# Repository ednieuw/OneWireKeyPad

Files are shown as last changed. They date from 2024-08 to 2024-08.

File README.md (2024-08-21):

# 1x3 and 4x3 membrane keypad controlled with one wire to the analog pin

[Page as PDF](https://github.com/ednieuw/OneWireKeyPad/blob/main/One%20wire%203x4%20keypad.pdf)
<table>
<tr>
 <td>This page describes how to wire the output pins of a:<br />
<br />
- seven 
pins, 3 columns * 4 rows key pad <br />
<br />
<br />
and a <br />
</td>
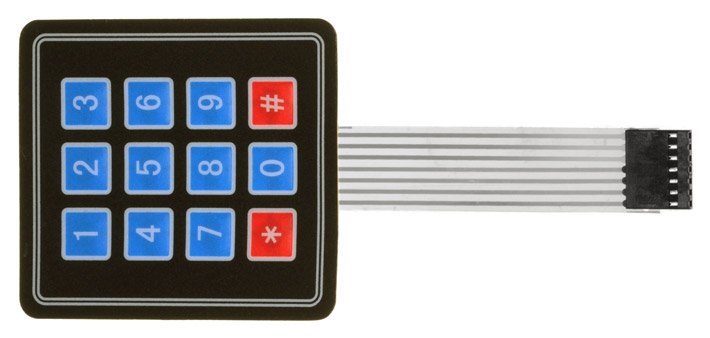
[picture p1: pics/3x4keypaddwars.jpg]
keypad
<td></td>
</tr>
<tr>
<td>
- four pins three button 3 x 1 keypad, <br />
	<br />
to an one wire analogue output.
	</td>
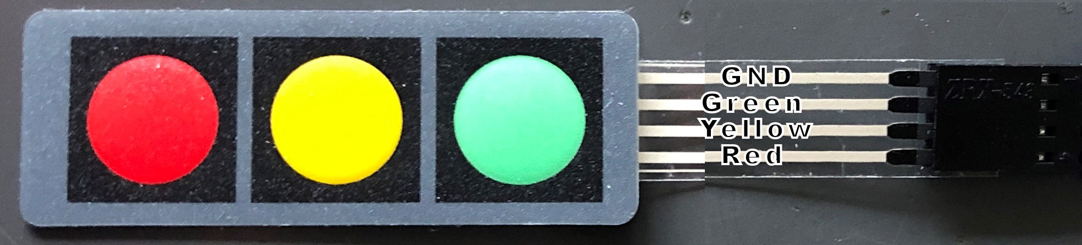
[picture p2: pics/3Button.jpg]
keypad 3b
<td></td>
	</tr>
</table>
<br />
The addition of a few resistors converts the key pads to one wire and saves 
many digital pins at the cost one analogue pin.<br />
Libraries are not needed anymore and will save many memory bytes but lacking 
interrupt driven detection of operation of the key pad. <br />
But processors are very fast and in many programs it is possible to check the 
buttons more than 1000 times a second.<br />
The three button key pad is a nice, flat, replacement of a rotary encoder saving 
three digital pins, a library and 1500 bytes.</p>
<br />
Three different resistor resistances are used.<br />
This page:
<a href="http://www.circuitbasics.com/how-to-set-up-a-keypad-on-an-arduino/">
http://www.circuitbasics.com/how-to-set-up-a-keypad-on-an-arduino/</a>
explains how the key pad works.<br />
<br />
There are many tutorials how to make a one-key wire keypad but or they use many 
resistors, make use of libraries or are hard to follow.</p>
<p>
<table>
<tr>
	<td> In the picture on the right one can see that by 
	pressing a button a connection is made between a row and a column. <br />
	By choosing the right resistor combination the output will be different 
	for every button. <br />
	5V is connected to C1 and ground after a 1.1 kilo-ohm resistor.<br />
	When 3 is pressed the current flows from R1 tot C3 and flows to a 1.1 
	kilo-ohm resistor resulting in a reading of 989 bits. <br />
	Pressing * R4 and C1 and connected resulting in a flow through all the 
	resistors and a reading of 125 bits.<br />
	To discriminate between the buttons the difference between the 
	difference button must be as large as possible.<br />
	Because resistors of identical resistance value will not have exact the 
	same resistance measured, readings between modules will vary a little. 
	In the Arduino source code the range per button is large enough to 
	overcome these differences. </td>
	<td >
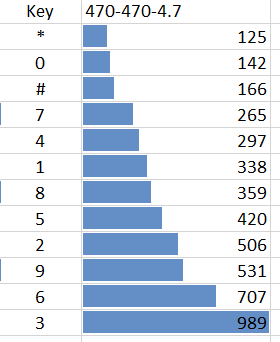
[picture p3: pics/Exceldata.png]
Analogue readings
 		</td>
	<td>
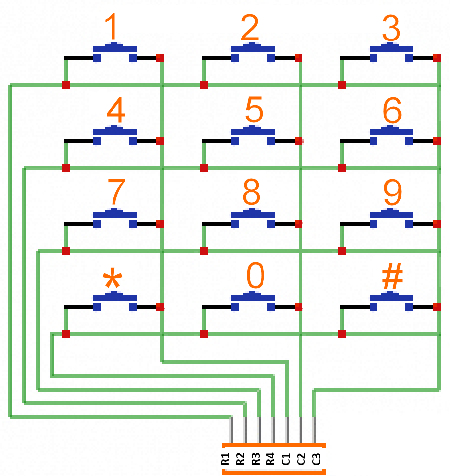
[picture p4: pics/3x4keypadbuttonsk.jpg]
Keys
		</td>
	</tr>

</table>
<p>
<table>
	<tr>
		<td>
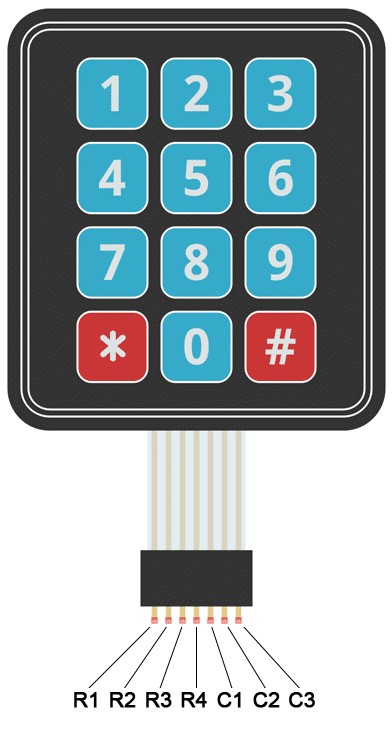
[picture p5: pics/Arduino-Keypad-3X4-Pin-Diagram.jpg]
3x4 Keypad
		</td>
		<td>
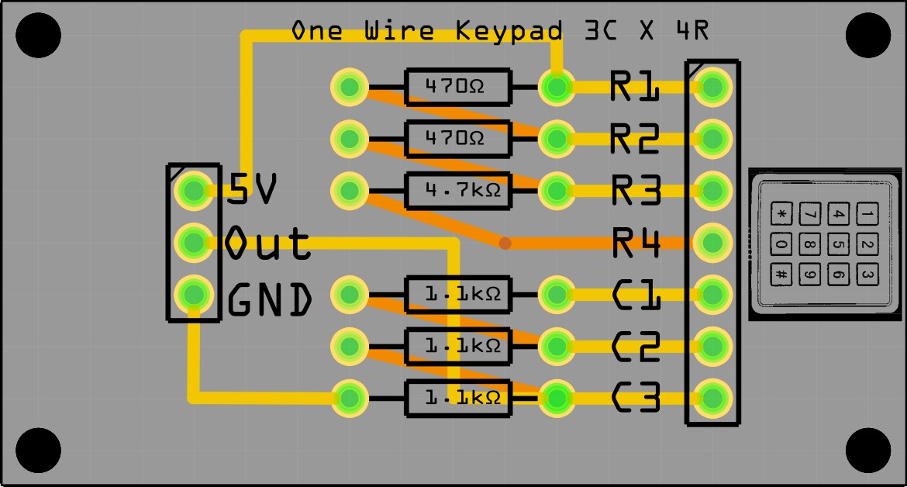
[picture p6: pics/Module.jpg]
Module
		</td>
	</tr>
	<tr>
		<td class="auto-style2"><br />
		Source code<br />
		<a href="OneWireKeyPad/OneWireKeyPad.ino">OneWireKeyPad.ino</a></td>
		<td class="auto-style2" style="width: 887px">
		<a href="OneWireKeyPad.fzz">OneWireKeyPad.fzz</a> Fritzing file<br />
		<br />
		Below the source code to read the key values</td>
	</tr>
</table>
<ul>
	<li>
	<pre>int sensorPin = A0;   // select the input pin for the potentiometer
int ledPin = 13;      // select the pin for the LED
int sensorValue = 0;  // variable to store the value coming from the sensor
byte keyvalue;

void setup() 
{
 pinMode(ledPin, OUTPUT);   // declare the ledPin as an OUTPUT:
 Serial.begin(9600); 
 Serial.println("Started. Press a key");
}

void loop() 
{
 sensorValue = analogRead(sensorPin); // read the value from the sensor:
 digitalWrite(ledPin, HIGH);          // turn the ledPin on
 switch(sensorValue)
  {
    case   0 ... 100:  keyvalue = 13; break;   // noise
    case 101 ... 132:  keyvalue = 12; break;   // * 
    case 133 ... 154:  keyvalue =  0; break;   // 0 
    case 155 ... 216:  keyvalue = 11; break;   // # 
    case 217 ... 281:  keyvalue =  7; break;   // 7 
    case 282 ... 318:  keyvalue =  4; break;   // 4 
    case 319 ... 349:  keyvalue =  1; break;   // 1 
    case 350 ... 390:  keyvalue =  8; break;   // 8 
    case 391 ... 463:  keyvalue =  5; break;   // 5 
    case 464 ... 519:  keyvalue =  2; break;   // 2 
    case 520 ... 619:  keyvalue =  9; break;   // 9 
    case 620 ... 848:  keyvalue =  6; break;   // 6 
    case 849 ... 1023: keyvalue =  3; break;   // 3
  }
 if(keyvalue&lt;13) { Serial.println(keyvalue); delay(300); }
 digitalWrite(ledPin, LOW);   // turn the ledPin off:
}</pre>
	</li>
</ul>
<p>
<o:p><span class="auto-style2"><br />
<o:p><strong>3 X 1 key pad<br />
<br />
</strong>I use this key pad instead of a rotary encoder.
<table >
	<tr>
	<td colspan="2">
	<a href="pics/3-button-OneWire.jpg">
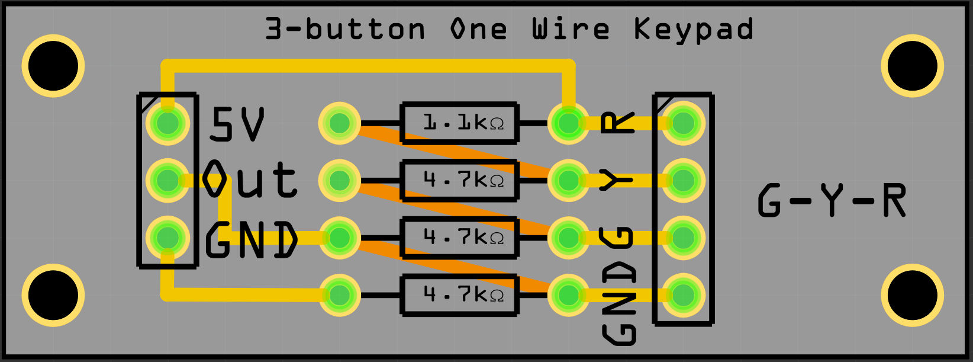
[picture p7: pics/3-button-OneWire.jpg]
PCB
	</a>
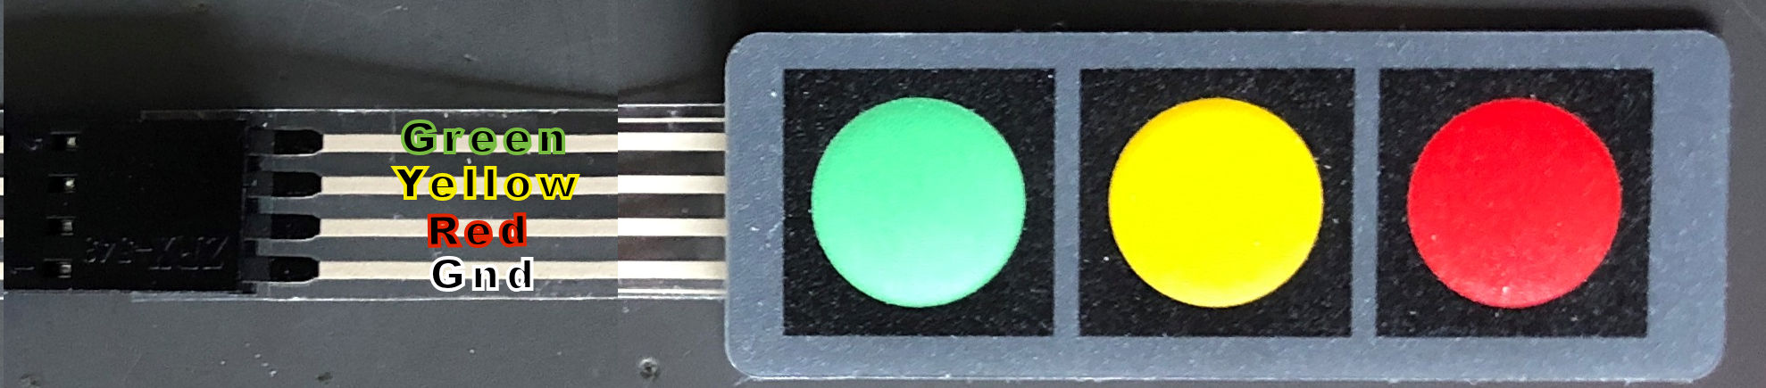
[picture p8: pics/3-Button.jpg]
3-button
	</td>
	</tr>
	<tr>
		<td>
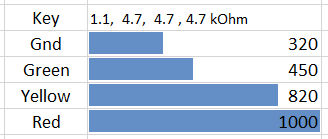
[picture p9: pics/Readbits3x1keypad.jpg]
Read bits
		</td>
		<td><a href="3-button-OneWire.jpg">
		PCB</a></td>
	</tr>
	<tr>
		<td>&nbsp;</td>
		<td>&nbsp;</td>
	</tr>
	<tr>
		<td>Source code: <a href="OneWireKeyPad3x1/OneWireKeyPad3x1.ino">
		OneWireKeyPad3x1.ino</a></td>
		<td>&nbsp;</td>
	</tr>
</table>
<br />
</o:p>
</span>
</o:p>
</span></p>
<pre>                           
//--------------------------------------------
// KEYPAD check for Onewire Keypad input with 5V and 1.1, 4.7, 4.7, 4.7 kOhm resistors
//--------------------------------------------
int sensorPin = A0;   // select the input pin for the potentiometer
int ledPin = 13;      // select the pin for the LED
int sensorValue = 0;  // variable to store the value coming from the sensor
char keyvalue;
char Key;
 </pre>
<pre>void setup() 
{
 pinMode(ledPin, OUTPUT);   // declare the ledPin as an OUTPUT:
 Serial.begin(9600); 
 Serial.println("Started. Press a key");
}</pre>
<pre>void loop() 
{
 sensorValue = analogRead(sensorPin); // read the value from the sensor:
 switch(sensorValue)
  {
    case   0 ... 385:  keyvalue = 99;            break;            // noise
    case 386 ... 635:  keyvalue = -1; Key = 'G'; break;            // G 
    case 636 ... 910:  keyvalue =  0; Key = 'Y'; break;            // Y 
    case 911 ... 1023: keyvalue =  1; Key = 'R'; break;            // R 
  }
 if(keyvalue&lt;2) 
   { 
    Serial.print(Key); Serial.print("  Read bits:"); Serial.println(sensorValue);
    digitalWrite(ledPin, HIGH);          // turn the ledPin on
    delay(300); 
    digitalWrite(ledPin, LOW);           // turn the ledPin off:
   }
}</pre>

<p>
<o:p>
<o:p></o:p>
<br />
<a href="FibonacciClockV039.zip">FibonacciClock 
software V039 + libraries for one wire 4x3 keypad</a></p>
Ed Nieuwenhuys, July 2022

Copied from my web site:
https://ednieuw.nl/Woordklok/OneWireKeyPad/OneWireKeyPad.html

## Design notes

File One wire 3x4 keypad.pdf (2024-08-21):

One Wire Key Pad

### This page describes how to wire the output pins of a:

### - seven pins, 3 columns * 4 rows key pad

### and a

- four pins three button 3 x 1 keypad,

to a one wire analogue output.

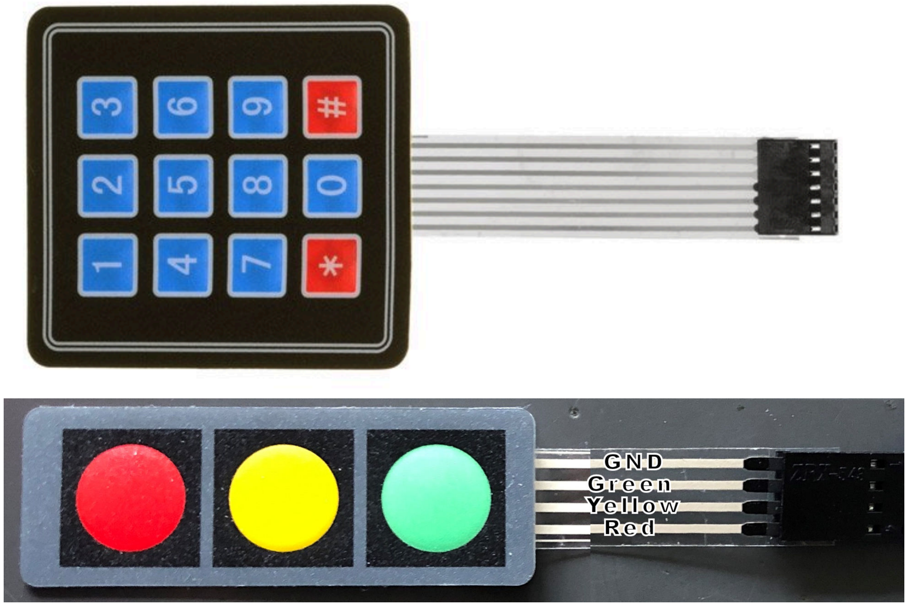
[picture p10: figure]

The addition with a few resistors converts the key pads to one wire and saves many digital pins at the cost one analogue pin. Libraries are not needed anymore and will save many memory bytes but lacking interrupt driven detection of operation of the key pad.
But processors are very fast and in many programs it is possible to check the buttons more than 1000 times a second.
The three button key pad is a nice, flat, replacement of a rotary encoder saving three digital pins, a library and 1500 bytes.

### 3 X 4 key pad

Three different resistor resistances are used.
This page: http://www.circuitbasics.com/how-to-set-up-a-keypad-on-an-arduino/ explains nicely how the key pad works.

There are many tutorials how to make a one-key wire keypad but or they use many resistors, make use of libraries or are hard to follow.

### In the picture on the right one can see that by pressing a button a connection is made

between a row and a column.

### By choosing the right resistor combination the

output will be different for every button.

### 5V is connected to C1 and ground after a 1.1 kilo-ohm resistor. When 3 is pressed the current flows from R1

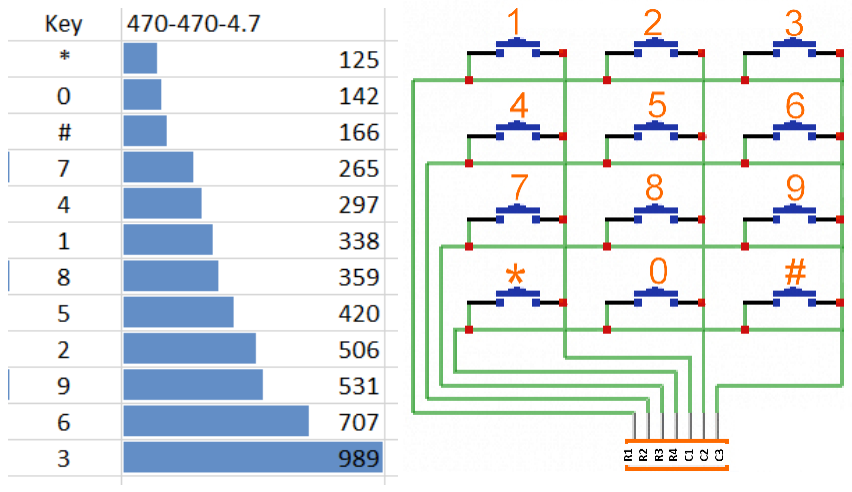
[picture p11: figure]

### tot C3 and flows to a 1.1 kilo-ohm resistor

resulting in a reading of 989 bits.

### Pressing * R4 and C1 and connected resulting in a flow through all the resistors and a

reading of 125 bits.

### To discriminate between the buttons the difference between the difference button must

be as large as possible.

### Because resistors of identical resistance value will not have exact the same resistance measured, readings between modules will vary a little. In the Arduino source code the range per button is large enough to overcome these

differences.

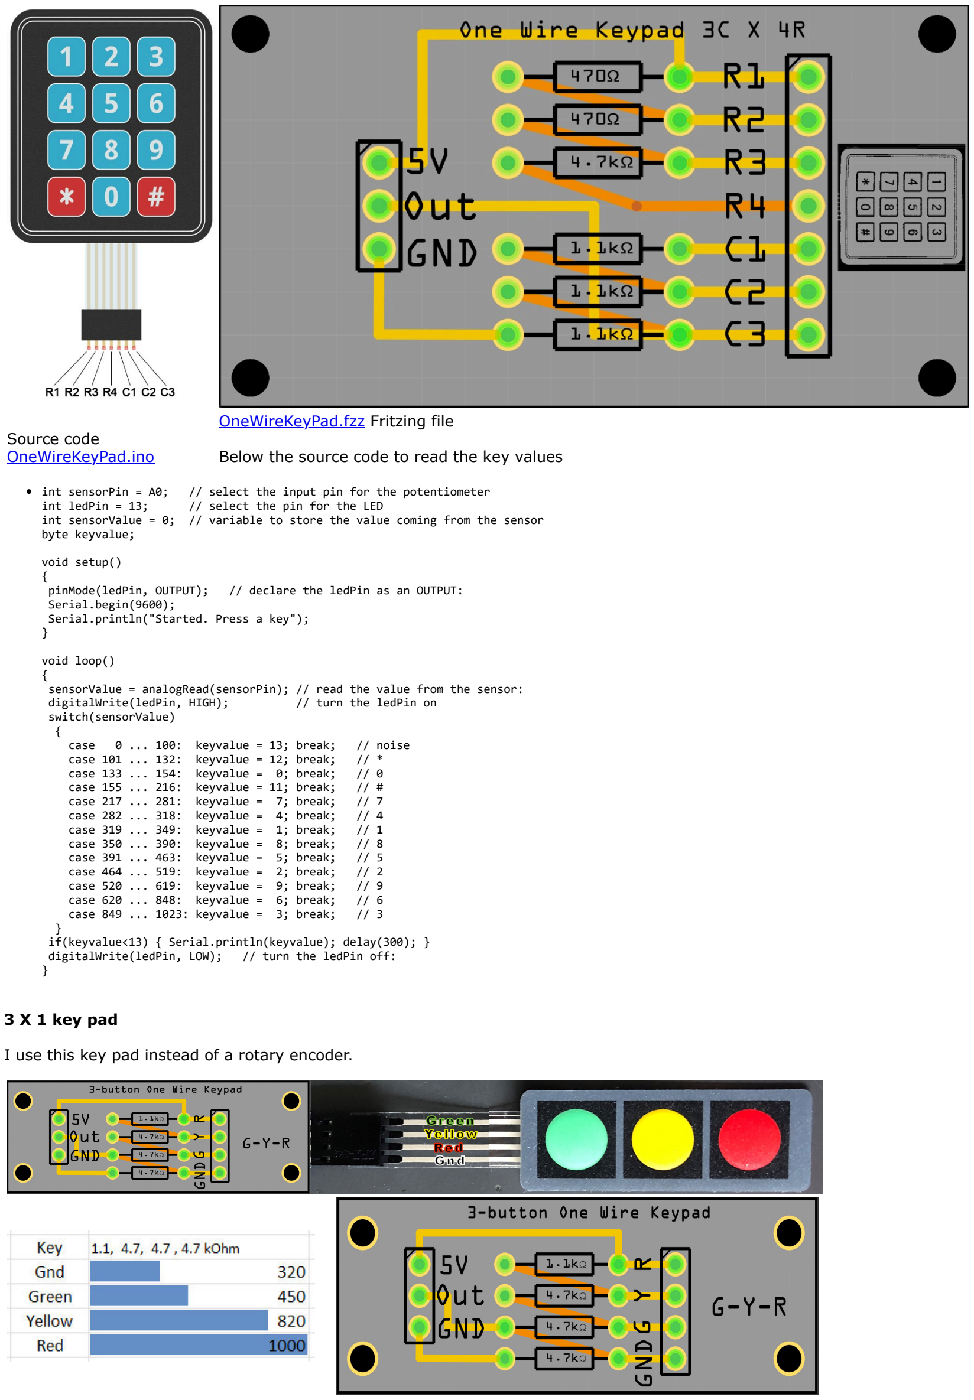
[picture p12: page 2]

### Source code

OneWireKeyPad.ino (https://ednieuw.home.xs4all.nl/Woordklok/OneWireKeyPad/OneWireKeyPad/OneWireKeyPad.ino)

OneWireKeyPad.fzz (https://ednieuw.home.xs4all.nl/Woordklok/OneWireKeyPad/OneWireKeyPad.fzz) Fritzing file

### Below the source code to read the key values

int sensorPin = A0; | // select the input pin for the potentiometer
int ledPin = 13; | // select the pin for the LED
int sensorValue = 0; // variable to store the value coming from the sensor byte keyvalue;

void setup()
{
pinMode(ledPin, OUTPUT); // declare the ledPin as an OUTPUT: Serial.begin(9600);
Serial.println("Started. Press a key");
}

void loop()
{
sensorValue = analogRead(sensorPin); // read the value from the sensor:
digitalWrite(ledPin, HIGH); | // turn the ledPin on
switch(sensorValue)
{
case | 0 ... 100: keyvalue = 13; break; | // noise
case 101 ... 132: keyvalue = 12; break; | // *
case 133 ... 154: keyvalue = 0; break; | // 0
case 155 ... 216: keyvalue = 11; break; | // #
case 217 ... 281: keyvalue = 7; break; | // 7
case 282 ... 318: keyvalue = 4; break; | // 4
case 319 ... 349: keyvalue = 1; break; | // 1
case 350 ... 390: keyvalue = 8; break; | // 8
case 391 ... 463: keyvalue = 5; break; | // 5
case 464 ... 519: keyvalue = 2; break; | // 2
case 520 ... 619: keyvalue = 9; break; | // 9
case 620 ... 848: keyvalue = 6; break; | // 6
case 849 ... 1023: keyvalue = 3; break; | // 3
}
if(keyvalue<13) { Serial.println(keyvalue); delay(300); } digitalWrite(ledPin, LOW); // turn the ledPin off:
}

### 3 X 1 key pad

I use this key pad instead of a rotary encoder.

Source code: OneWireKeyPad3x1.ino (https://ednieuw.home.xs4all.nl/Woordklok/OneWireKeyPad/OneWireKeyPad3x1/OneWireKeyPad3x1.ino)

//--------------------------------------------
// KEYPAD check for Onewire Keypad input with 5V and 1.1, 4.7, 4.7, 4.7 kOhm resistors //--------------------------------------------
int sensorPin = A0; | // select the input pin for the potentiometer
int ledPin = 13; | // select the pin for the LED
int sensorValue = 0; // variable to store the value coming from the sensor char keyvalue;
char Key;

void setup()
{
pinMode(ledPin, OUTPUT); // declare the ledPin as an OUTPUT: Serial.begin(9600);
Serial.println("Started. Press a key");
}

void loop()
{
sensorValue = analogRead(sensorPin); // read the value from the sensor: switch(sensorValue)
{
case | 0 ... 385: keyvalue = 99; | break; | // noise
case 386 ... 635: keyvalue = -1; Key = 'G'; break; | // G
case 636 ... 910: keyvalue = 0; Key = 'Y'; break; | // Y
case 911 ... 1023: keyvalue = 1; Key = 'R'; break; | // R
}
if(keyvalue<2)
{
Serial.print(Key); Serial.print(" Read bits:"); Serial.println(sensorValue);
digitalWrite(ledPin, HIGH); | // turn the ledPin on
delay(300);
digitalWrite(ledPin, LOW); | // turn the ledPin off:
}
}

FibonacciClock software V039 + libraries for one wire 4x3 keypad (https://ednieuw.home.xs4all.nl/Woordklok/OneWireKeyPad/FibonacciClockV039.zip)

### Ed Nieuwenhuys, July 2022, March 2021

November 2019

### < -- Back to start (https://ednieuw.home.xs4all.nl/Woordklok/index.html)

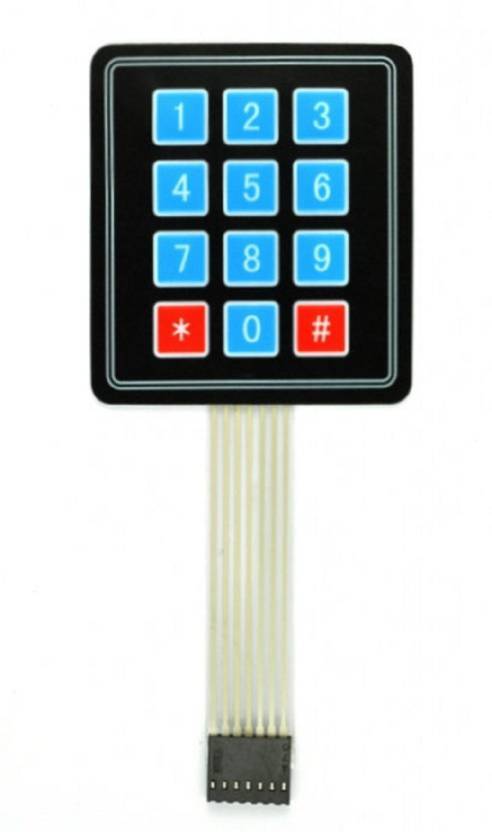
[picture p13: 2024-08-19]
pics/3x4keypad.jpg

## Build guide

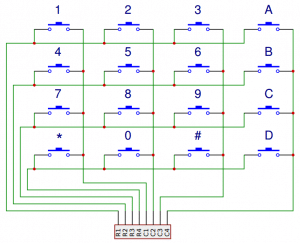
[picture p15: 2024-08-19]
pics/Arduino-Keypad-Tutorial-4X4-Keypad-Schematic-300x243.png
